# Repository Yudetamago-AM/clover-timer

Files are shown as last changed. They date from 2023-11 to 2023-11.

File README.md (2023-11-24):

# clover-timer
Simple Countdown Timer using Padauk MCU

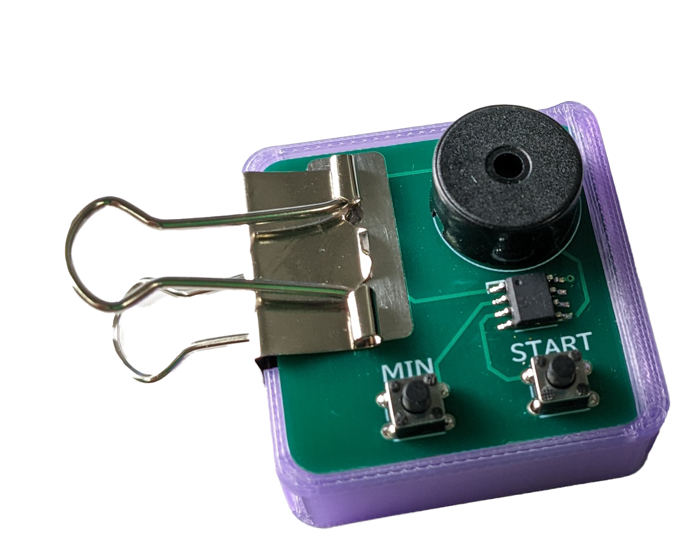
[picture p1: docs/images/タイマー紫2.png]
タイマー


## Docs
- [組み立て方（Japanese）](./docs/assembly-instruction.pdf)
- [補足資料（Japanese）](./docs/assembly-instruction-short.pdf)

## Schematic
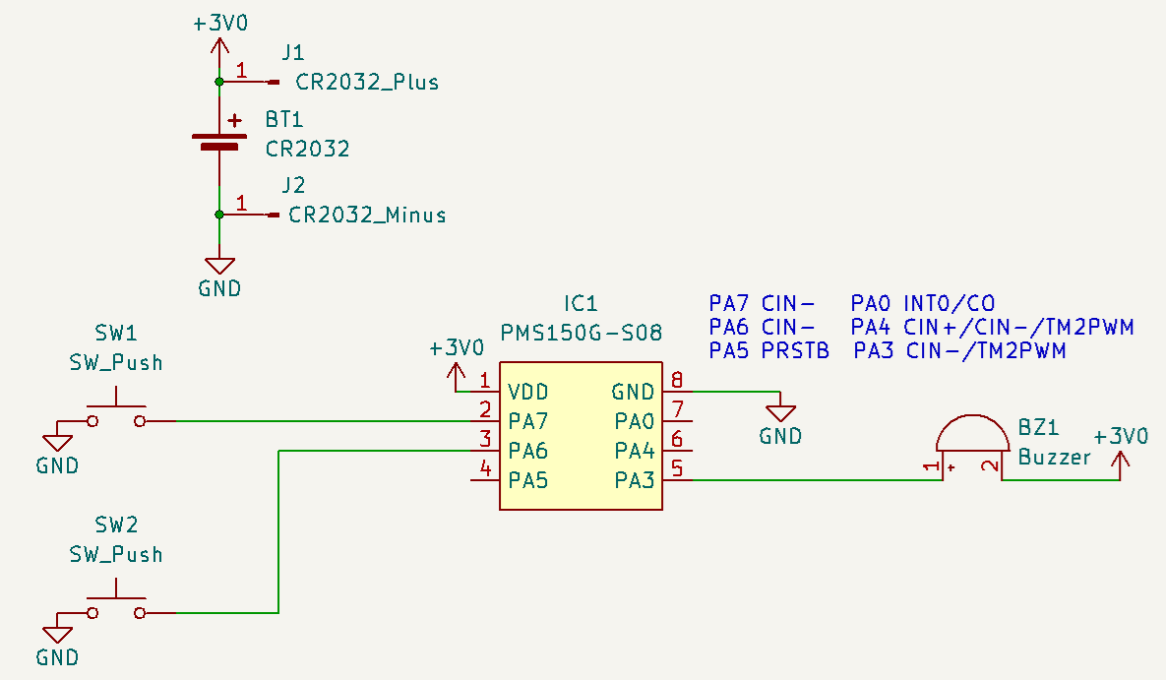
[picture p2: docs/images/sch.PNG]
schematic

Only supports PMS150G for now, but should be able to run on other Padauk MCUs with modifications.

### Power Consumption
- 350 μA (Countdown)
- 55  μA (Sleep)

Fall sleep in 2.5s

## BOM
| Ref | Part # | Description | Purchase | Price |
| --- | --- | --- | --- | ----- |
| IC1 | Padauk PMS150G | MCU | [LCSC](https://www.lcsc.com/product-detail/Microcontroller-Units-MCUs-MPUs-SOCs_PADAUK-Tech-PMS150G-S08_C2909819.html) | $0.04 each |
| SW1, SW2| TS4548CJ | Push Switch. Others are OK (Check footprint) | [LCSC](https://www.lcsc.com/product-detail/_SHOU-HAN-_C5359333.html) | $0.008 each |
| BZ1 | SFN-1407PA7.6 | Passive Buzzer | [LCSC](https://www.lcsc.com/product-detail/_S-S-_C360603.html) | $0.05 each |
| Battery | CR2032 | 3V Litium Battery Cell | - | $0.1~ each |
| - | Case | 3D printed case | Print by yourself | [STL](./case/bottom_rev0f.stl) |
| - | Binder Clip | Clip for Battery Case | - | $0.05~  each|
| - | Jigu(Optional) | Cardboard Jigu for Battery Case | Cut by yourself | [Data](./case/jigu_laser_rev2.dxf) |
| - | Magnet(Optional) | Φ18*5mm Magnet | - | $0.05~ each |

## Usage

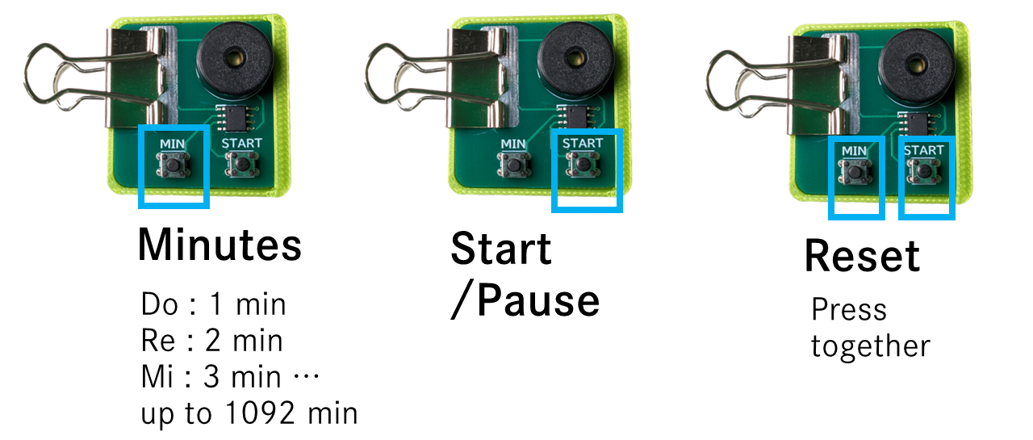
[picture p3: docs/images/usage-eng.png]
usage


## License
GPLv3

This project is based on:
- [Padauk-tone](https://github.com/Kashouryo/Padauk-tone) by Kashouryo, MIT License
- [pdk-digital-clock](https://github.com/serisman/pdk-digital-clock) by serisman, GPLv3

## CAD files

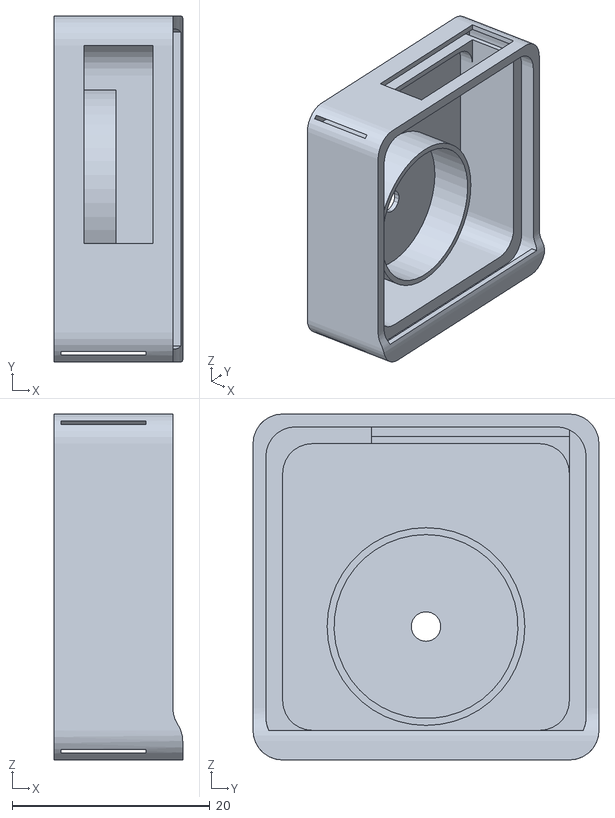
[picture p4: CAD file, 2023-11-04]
case/bottom_rev0f.stl
13.0 x 35.0 x 35.0

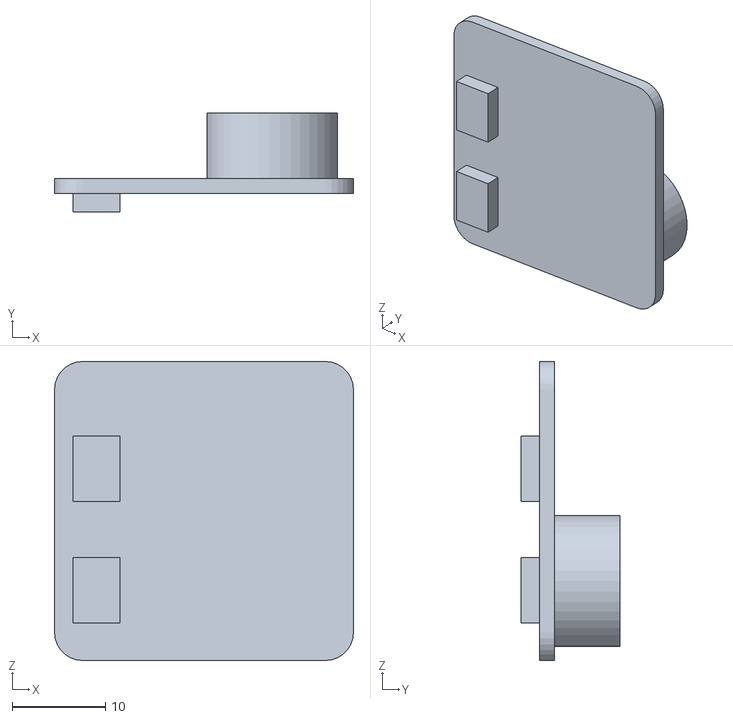
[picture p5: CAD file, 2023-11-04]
case/pcb_abs2.stl
32.0 x 10.6 x 32.0

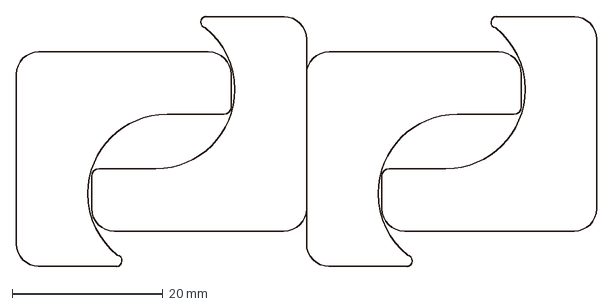
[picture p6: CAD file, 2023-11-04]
case/jigu_laser_rev2.dxf
77.0 x 33.2 mm

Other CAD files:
case/bottom_rev0f.ipt
case/pcb_abs.ipt

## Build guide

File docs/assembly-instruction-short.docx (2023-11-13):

「はんだ付けを体験しよう！」配付資料　　　　　　　　　　　　　　　　センサー街道プロジェクト

はんだ付けのやり方

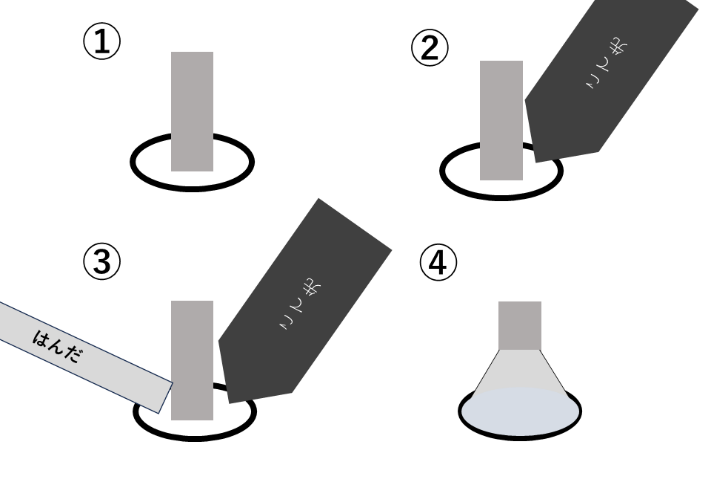
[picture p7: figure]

1. はんだ付け

背の低い部品から一つずつはんだ付けします。

  1 スイッチ→②ブザーの順です。

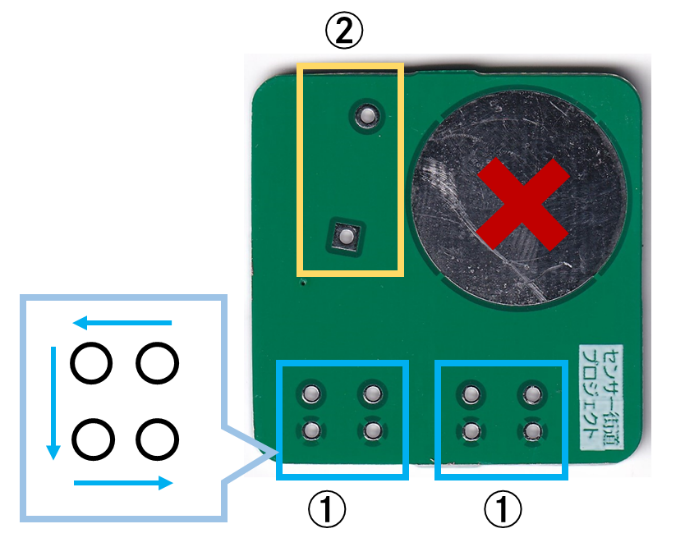
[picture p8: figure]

2. 組み立て
  1 磁石を押し込む かたいので、手伝います
  2 ジグをはめる

段ボールで できています。

  3 ボタン電池を入れる

磁石側が+です。

  4 基板をはめる
  5 クリップを付ける

電池ボックスと基板の固定の役割があります。

3. 使い方

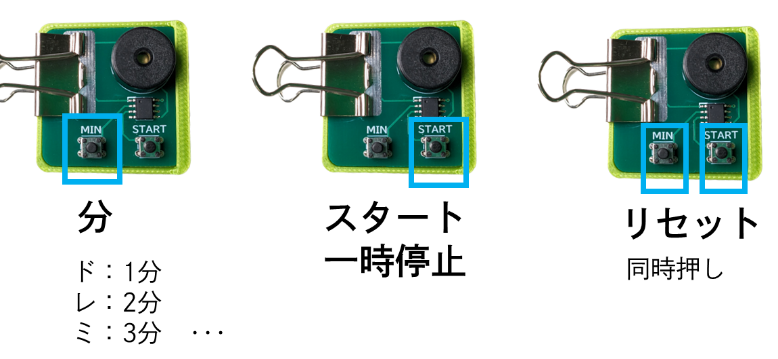
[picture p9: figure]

4. 仕様

使用電池 | CR2032 | スーパー等で売っています
消費電流 | 300μA | カウント時
消費電流 | 55μA | 待機時

5. ハードウェア構成

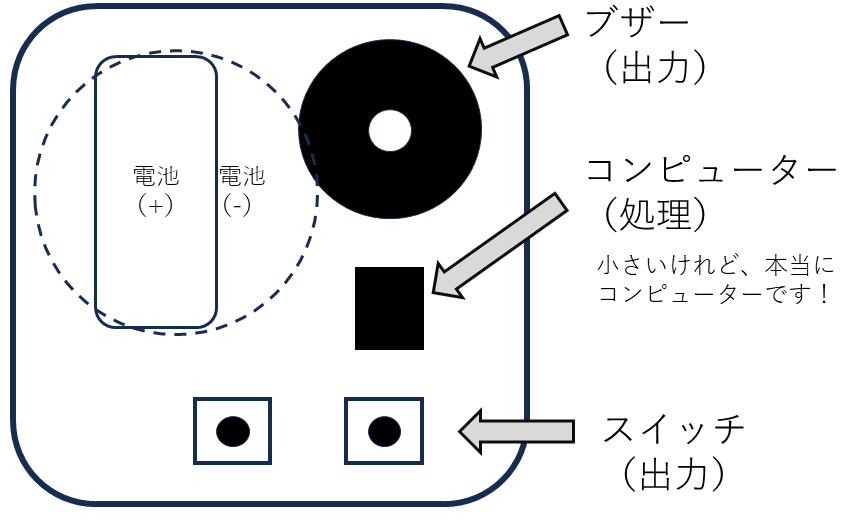
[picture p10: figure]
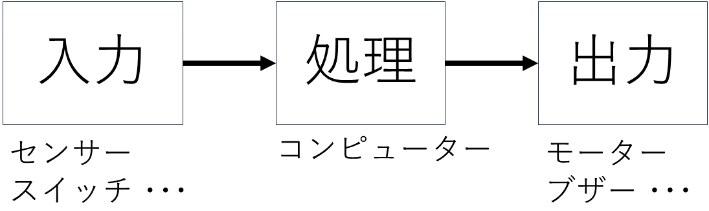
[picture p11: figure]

このタイマーと、スマートフォン、さらに自動車も本質的には同じ構成です。

6. 設計情報

このタイマーは、一定の条件下で誰でも自由に設計を利用・変更・再配布できます。

（ライセンス：GPLv3）

https://github.com/Yudetamago-AM/clover-timer

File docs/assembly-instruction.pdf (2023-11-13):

# はんだ付けを体験しよう！

センサー街道プロジェクト

京田辺校地総務課（同志社ローム記念館事務室）
同志社ローム記念館プロジェクト活動PR企画

内容

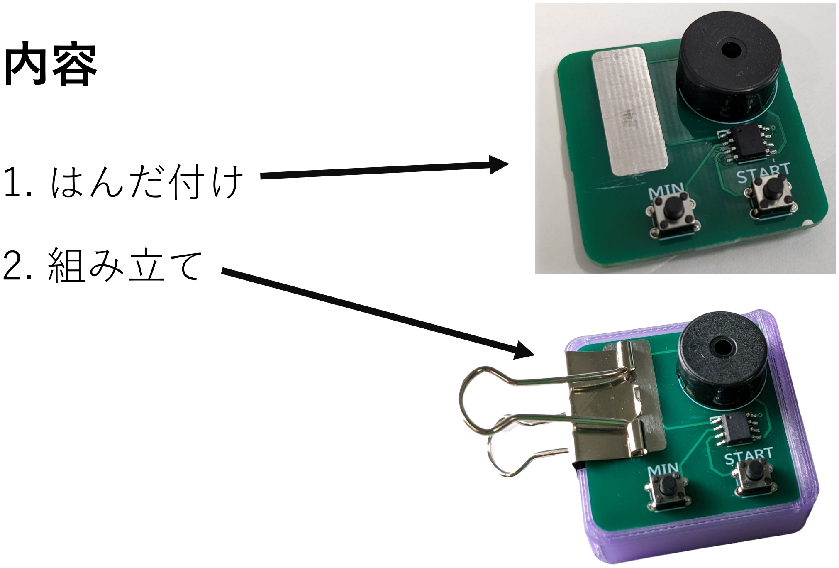
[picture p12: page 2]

## 1. はんだ付け 2. 組み立て

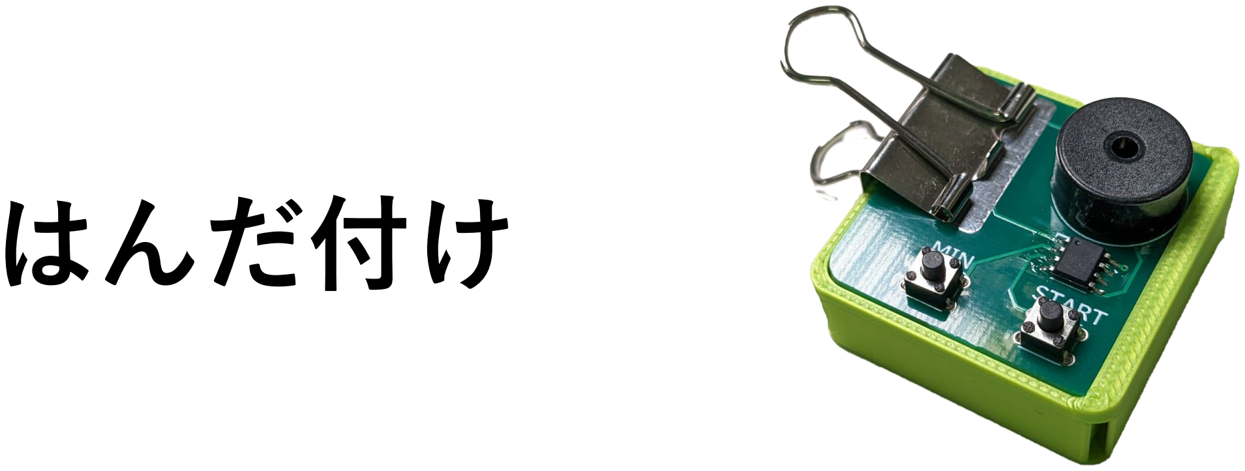
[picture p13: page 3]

# はんだ付け

# はんだごて

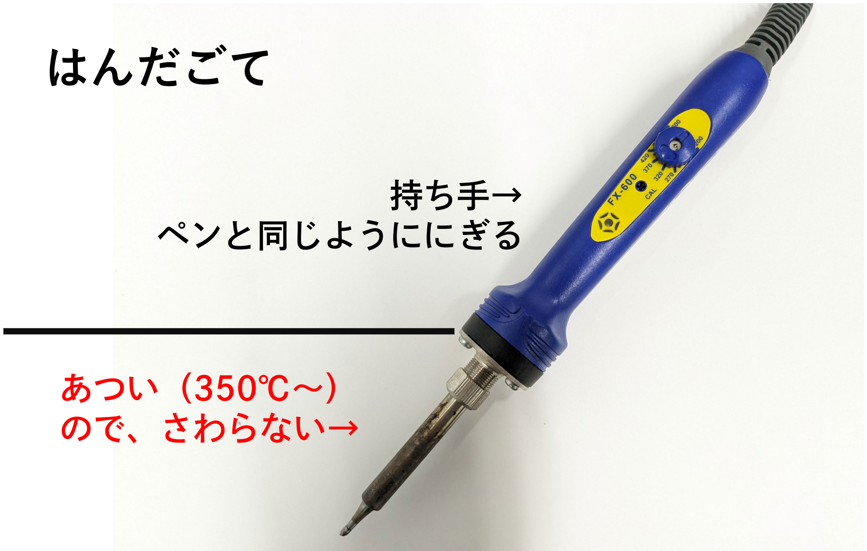
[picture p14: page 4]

### あつい（350℃～） ので、さわらない→

### 持ち手→ ペンと同じようににぎる

# はんだ付け

## 1. 部品をさしこむ

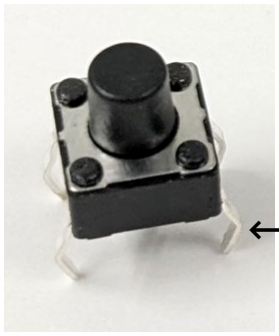
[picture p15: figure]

## 2. 部品の足をはんだ付けする

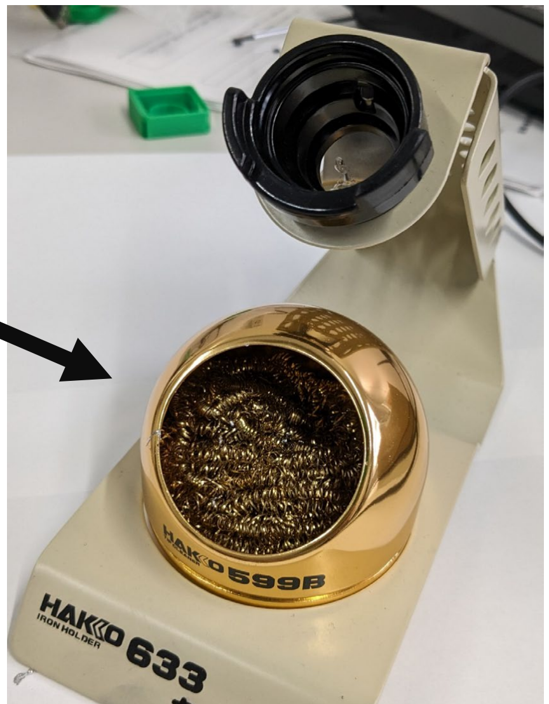
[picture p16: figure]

## 3. こて先をきれいにする

←足

# はんだ付けのやり方

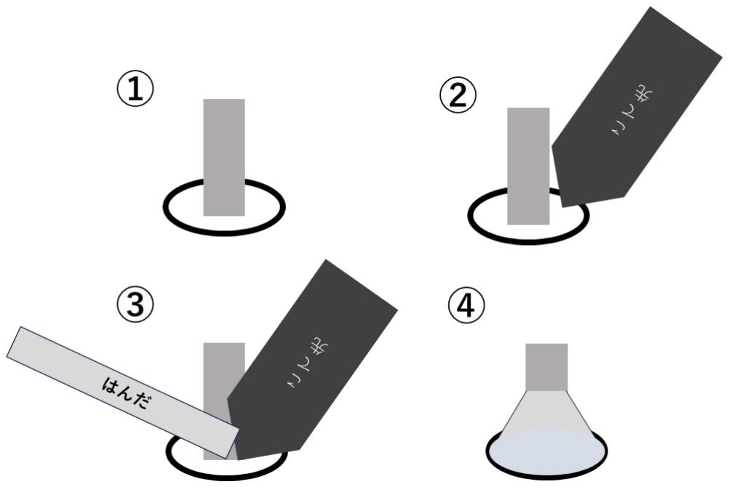
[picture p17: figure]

1. 部品を差し込み、基板（緑の
板）を裏返す
2. はんだごてのこて先を部品の足
と基板にあて予熱する
（1秒ほど）
3. 糸はんだを流し込む
4. 糸はんだとはんだごてを外し、
完成

部品

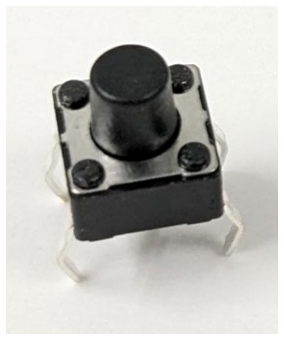
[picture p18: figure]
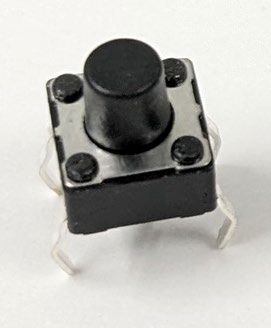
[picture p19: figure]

### 1. 押しボタン

2つ

### 2. ブザー

1つ

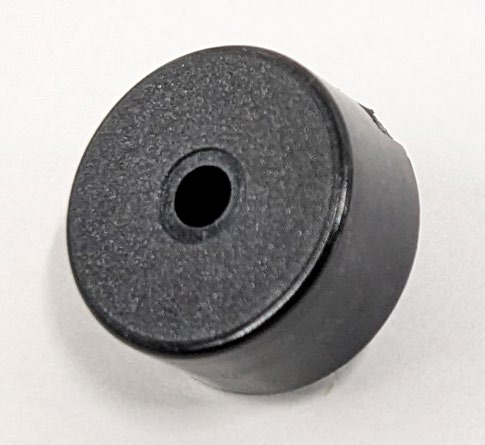
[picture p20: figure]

# はんだ付け

②

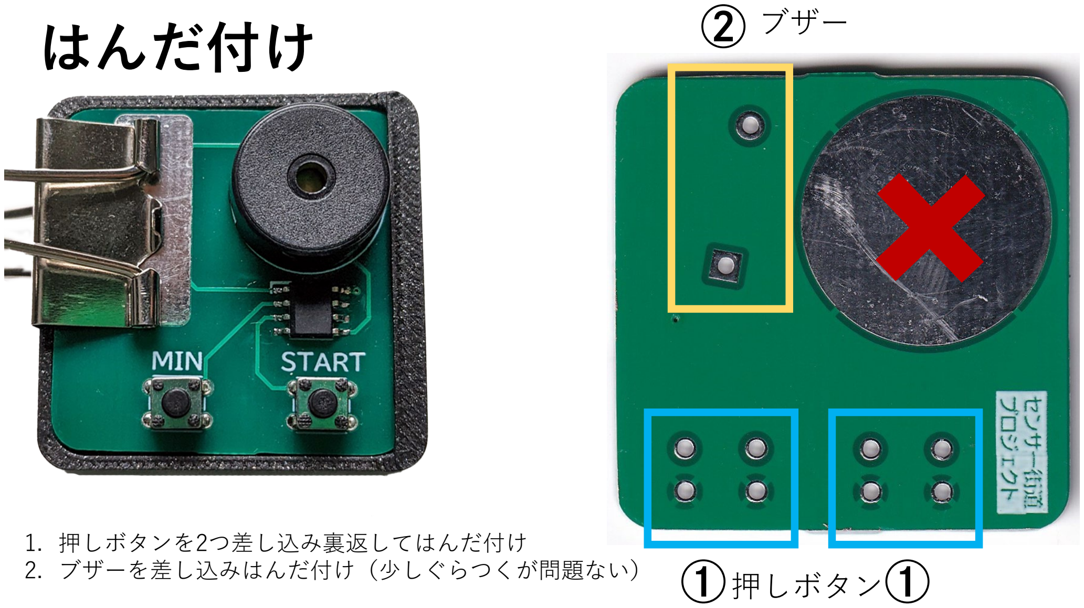
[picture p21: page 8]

① ①
押しボタン

ブザー

1. 押しボタンを2つ差し込み裏返してはんだ付け
2. ブザーを差し込みはんだ付け（少しぐらつくが問題ない）

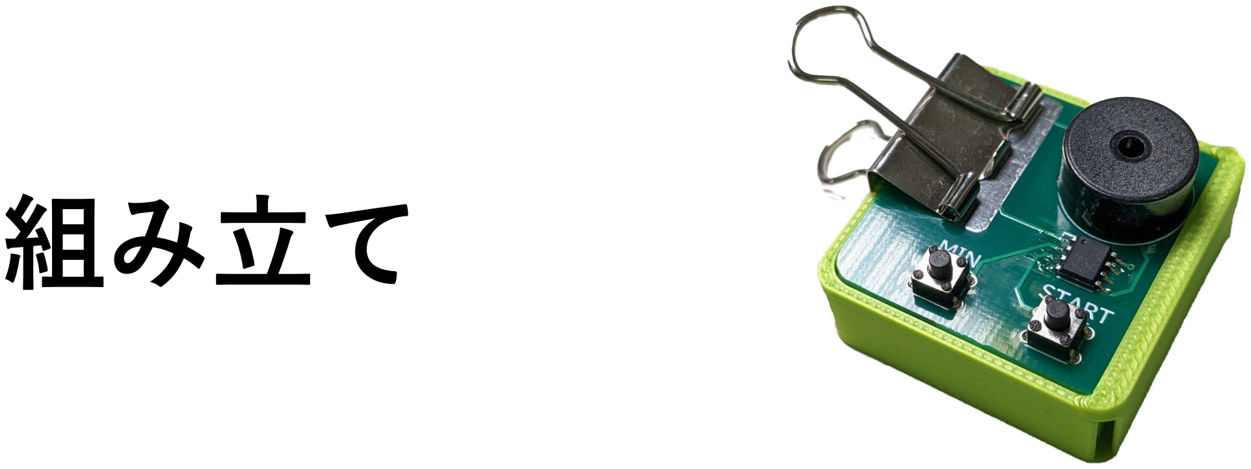
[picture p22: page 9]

# 組み立て

部品

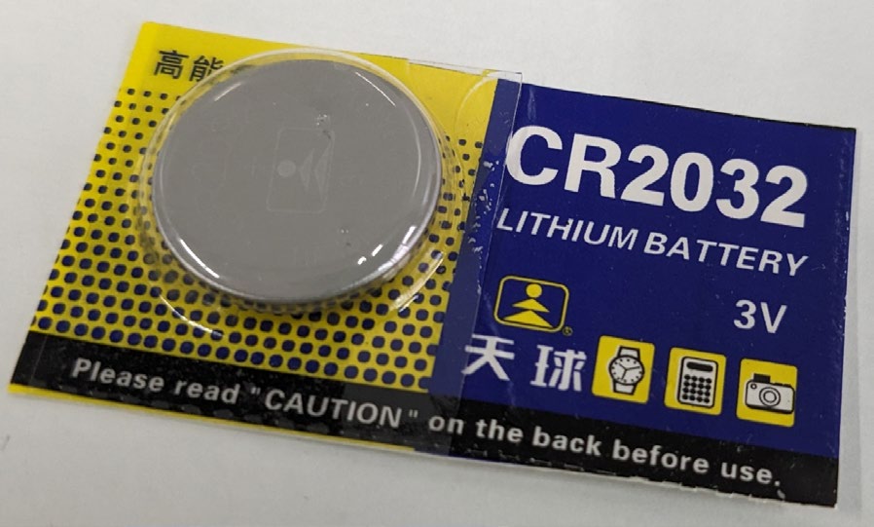
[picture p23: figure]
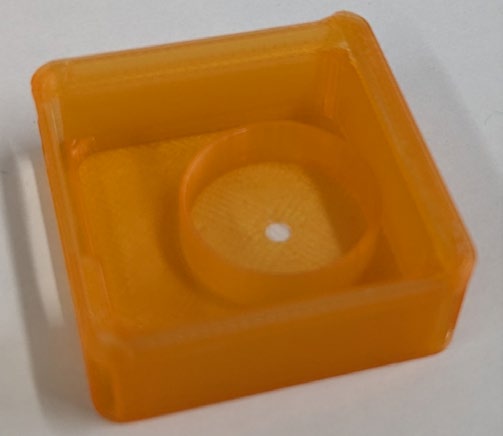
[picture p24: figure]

### 1. ケース

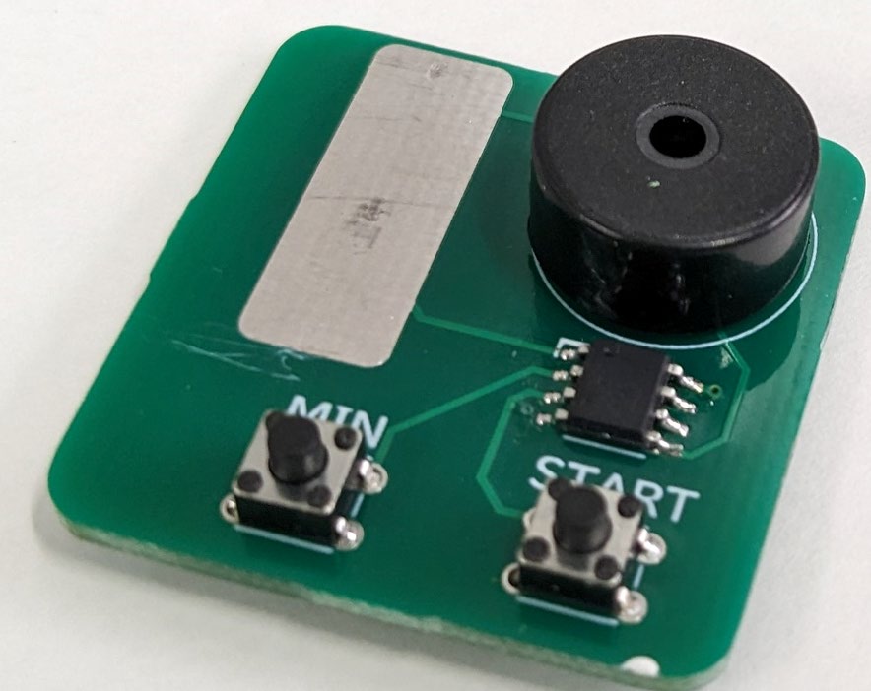
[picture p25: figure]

2. 磁石

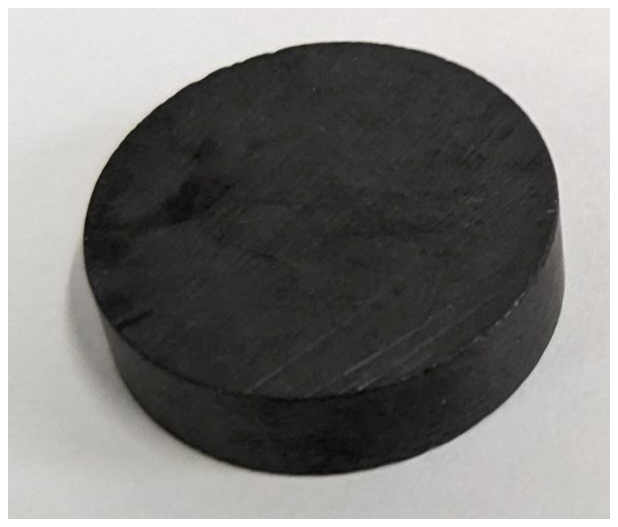
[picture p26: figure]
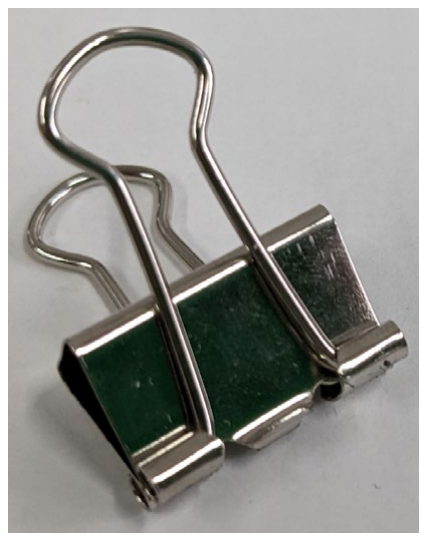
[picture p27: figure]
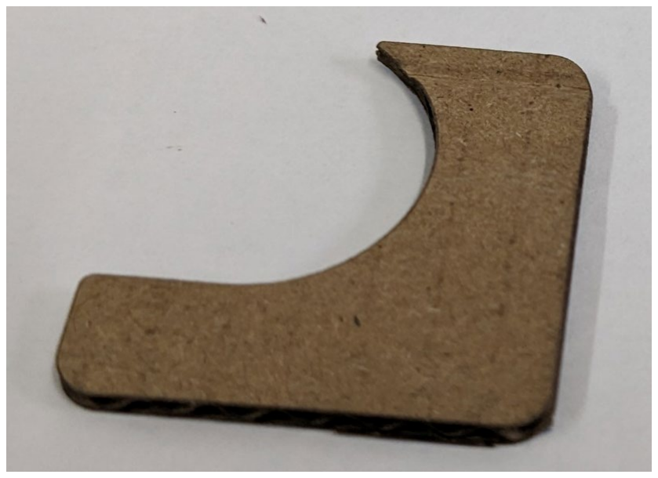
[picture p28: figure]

### 3. ジグ（治具）

### 4. ボタン電池

5. 基板

### 6. クリップ

# 磁石を押しこむ

### かたいので、手伝います （呼んでください！）

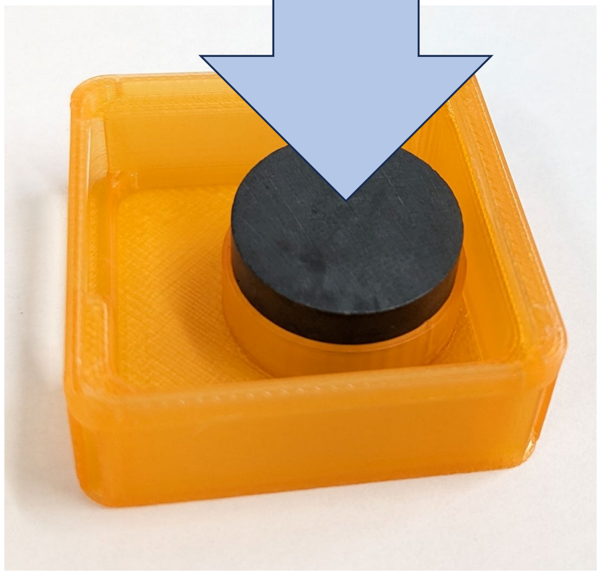
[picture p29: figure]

### 押し込んである場合は次へ

力

# ジグをはめる

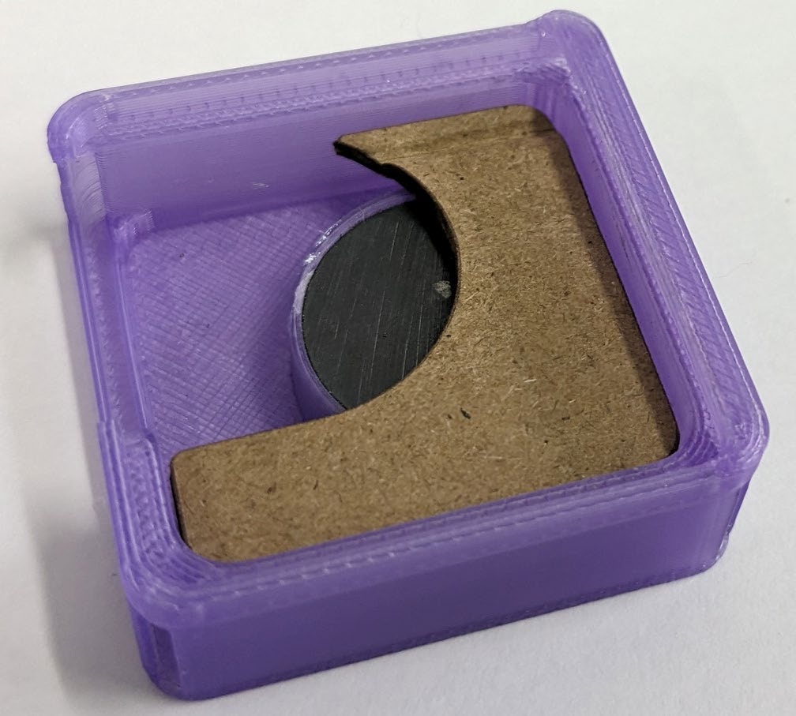
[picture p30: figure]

### - 向きに注意

# ボタン電池を入れる

ざらざらの面が表 | （開け方）

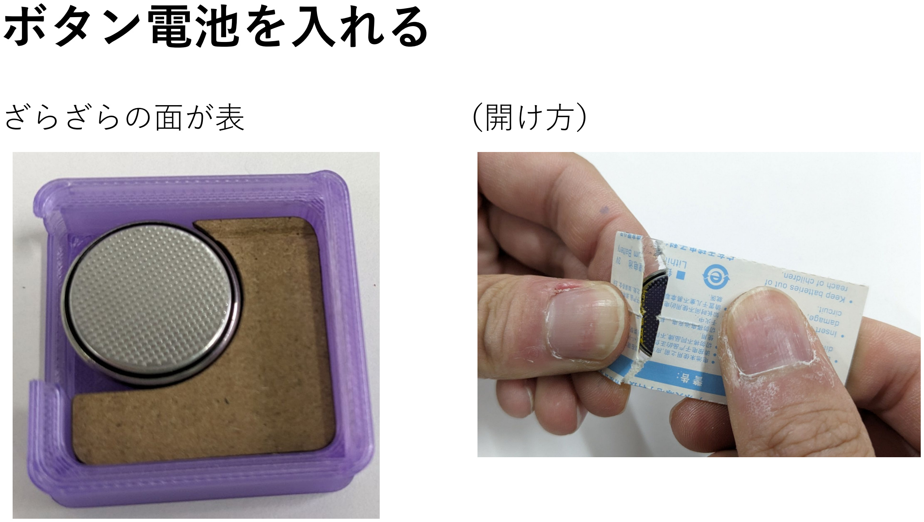
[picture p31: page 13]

# 基板をはめる ①

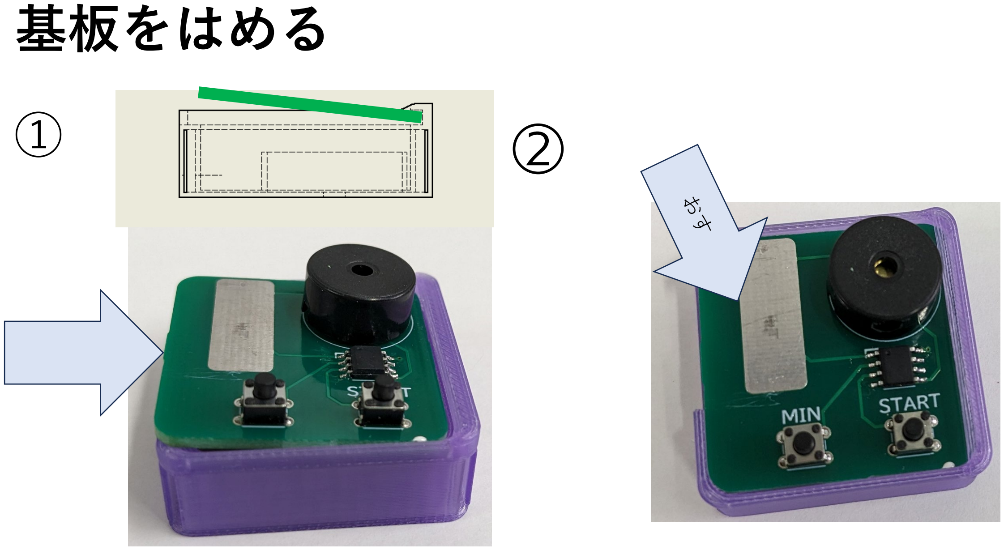
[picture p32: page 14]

②

# クリップをつける

### - ボタン電池と基板をはさむ

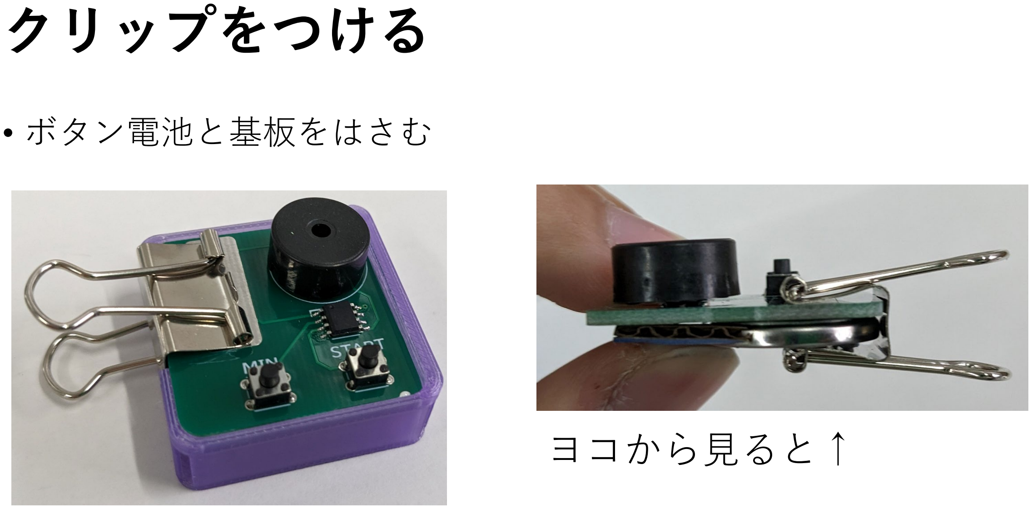
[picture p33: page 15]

## ヨコから見ると↑

# 使い方

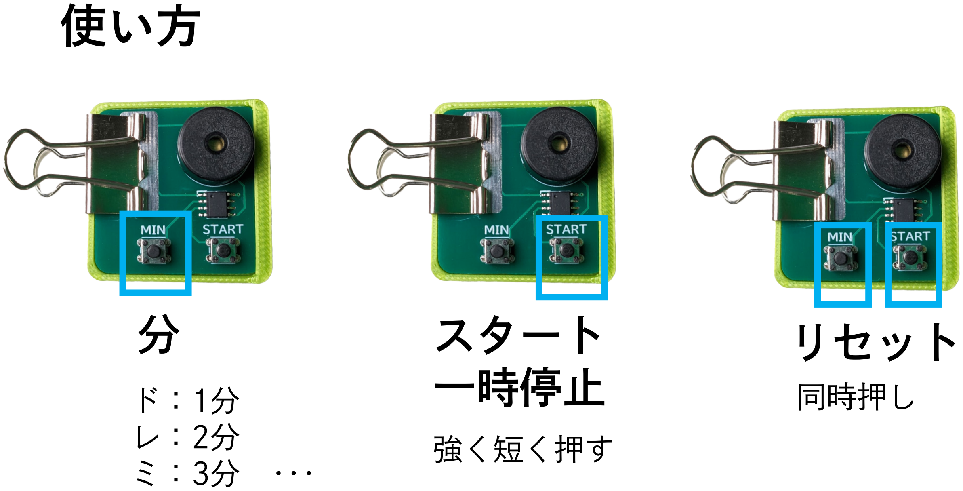
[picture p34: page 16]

分

ド：1分
レ：2分
ミ：3分 ･･･

## スタート 一時停止

## リセット

同時押し
強く短く押す

# トラブルシューティング

### - ボタンを押しても音が鳴らない

- ボタンのはんだ付けが不足しているかもしれません。ボタンの足の根 元にあてるイメージではんだ付けし直してみてください。

### - ボタンを押してないのに音が鳴り続ける

- ボタンのはんだ付けが多すぎるかもしれません。足と足の間がハンダ でつながってしまっていないか確認してください。
- はんだ吸い取り線などで、余分なはんだを取り除いてみてください。

# トラブルシューティング

### - 設定した時間になっても音が鳴らない

- スタートボタンを長く押しすぎてしまった（スタートして、一時停止 した）かも知れません。
- 一回、両方のボタンを押して、もう一度試してみてください。

# よくある質問

### - 何分まで測れる？

- 1092分まで
- 2^16=65536秒まで測れるので、65536/60 ≒ 1092分

### - 電池はどのくらい持つ？

- 150日くらい（のはず）
- ボタン電池(CR2023)の容量を220mAhとする。待機時55μA消費する。 動作している時間<<待機してる時間と考えて、
220m/55μ= 4000 時間、4000/24 ≒ 166日 自然放電もあると考えて、150日くらい？
- キット付属の電池は安いやつなので、そんなに持たないかも

完成！

### 1分にセットして音が鳴るかやってみましょう！

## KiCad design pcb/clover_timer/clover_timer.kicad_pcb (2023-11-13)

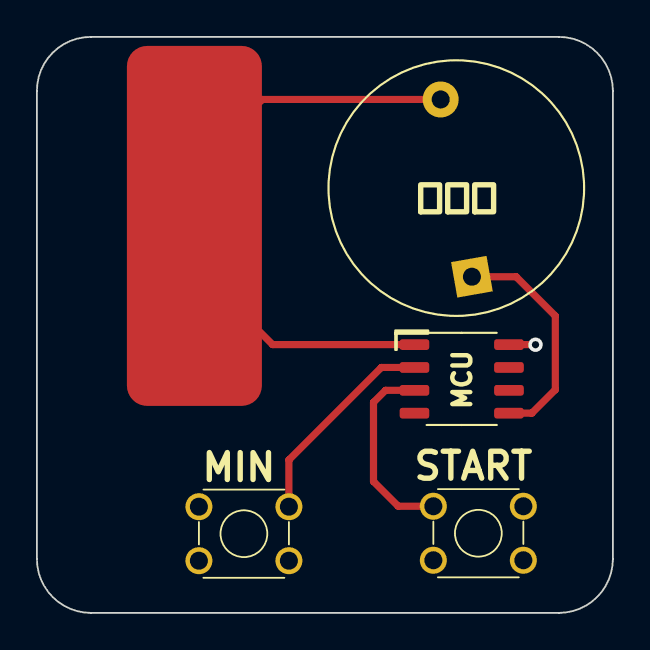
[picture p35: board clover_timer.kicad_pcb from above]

Board: 2 copper layers, 32.0 x 32.0 mm, 6 parts (1 on the bottom side), 5 nets.

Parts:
BZ1: Buzzer; Buzzer_D14mm_H7mm_P10mm
IC1: PMS150G-S08; SOP-8_3.9x4.9mm_P1.27mm
J1: CR2032_Plus
J2: CR2032_Minus; CR2032_GND
SW1, SW2: SW_Push; SW_TS4548CJ

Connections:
+3V0: BZ1.2 (+), IC1.1 (VDD), J1.1
GND: IC1.8 (GND), J2.1, SW1.1, SW2.1
unnamed: BZ1.1 (-), IC1.5 (PA3)
unnamed: IC1.3 (PA6), SW2.2
unnamed: IC1.2 (PA7), SW1.2

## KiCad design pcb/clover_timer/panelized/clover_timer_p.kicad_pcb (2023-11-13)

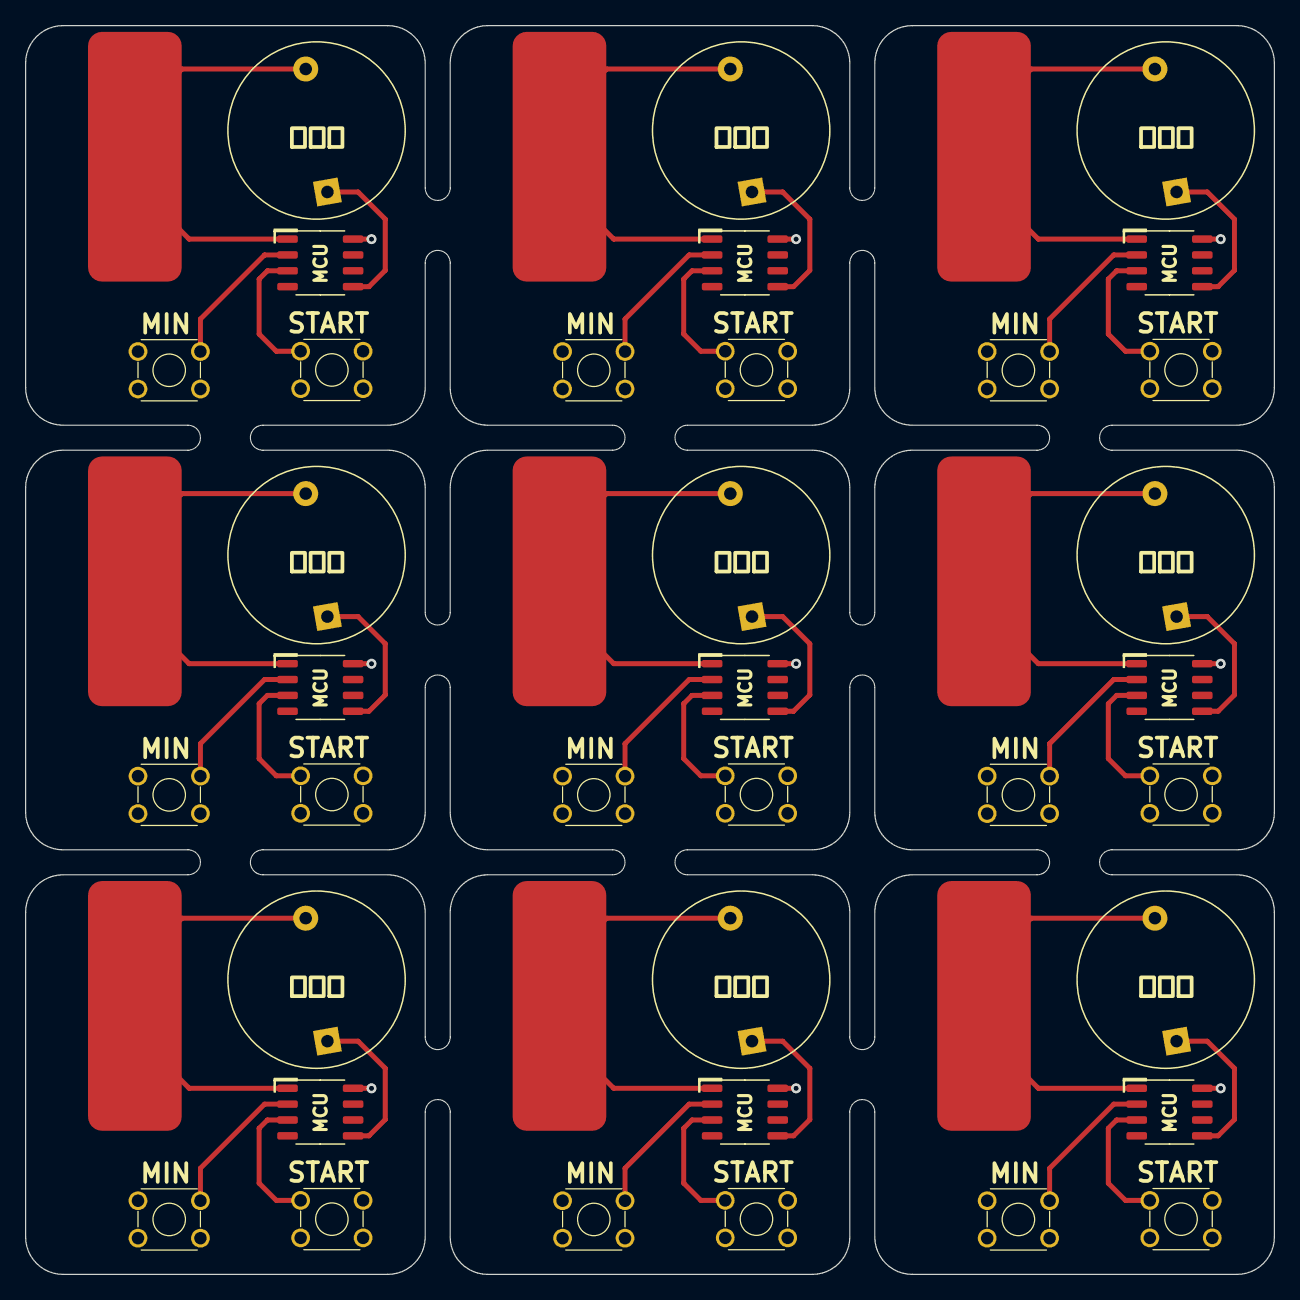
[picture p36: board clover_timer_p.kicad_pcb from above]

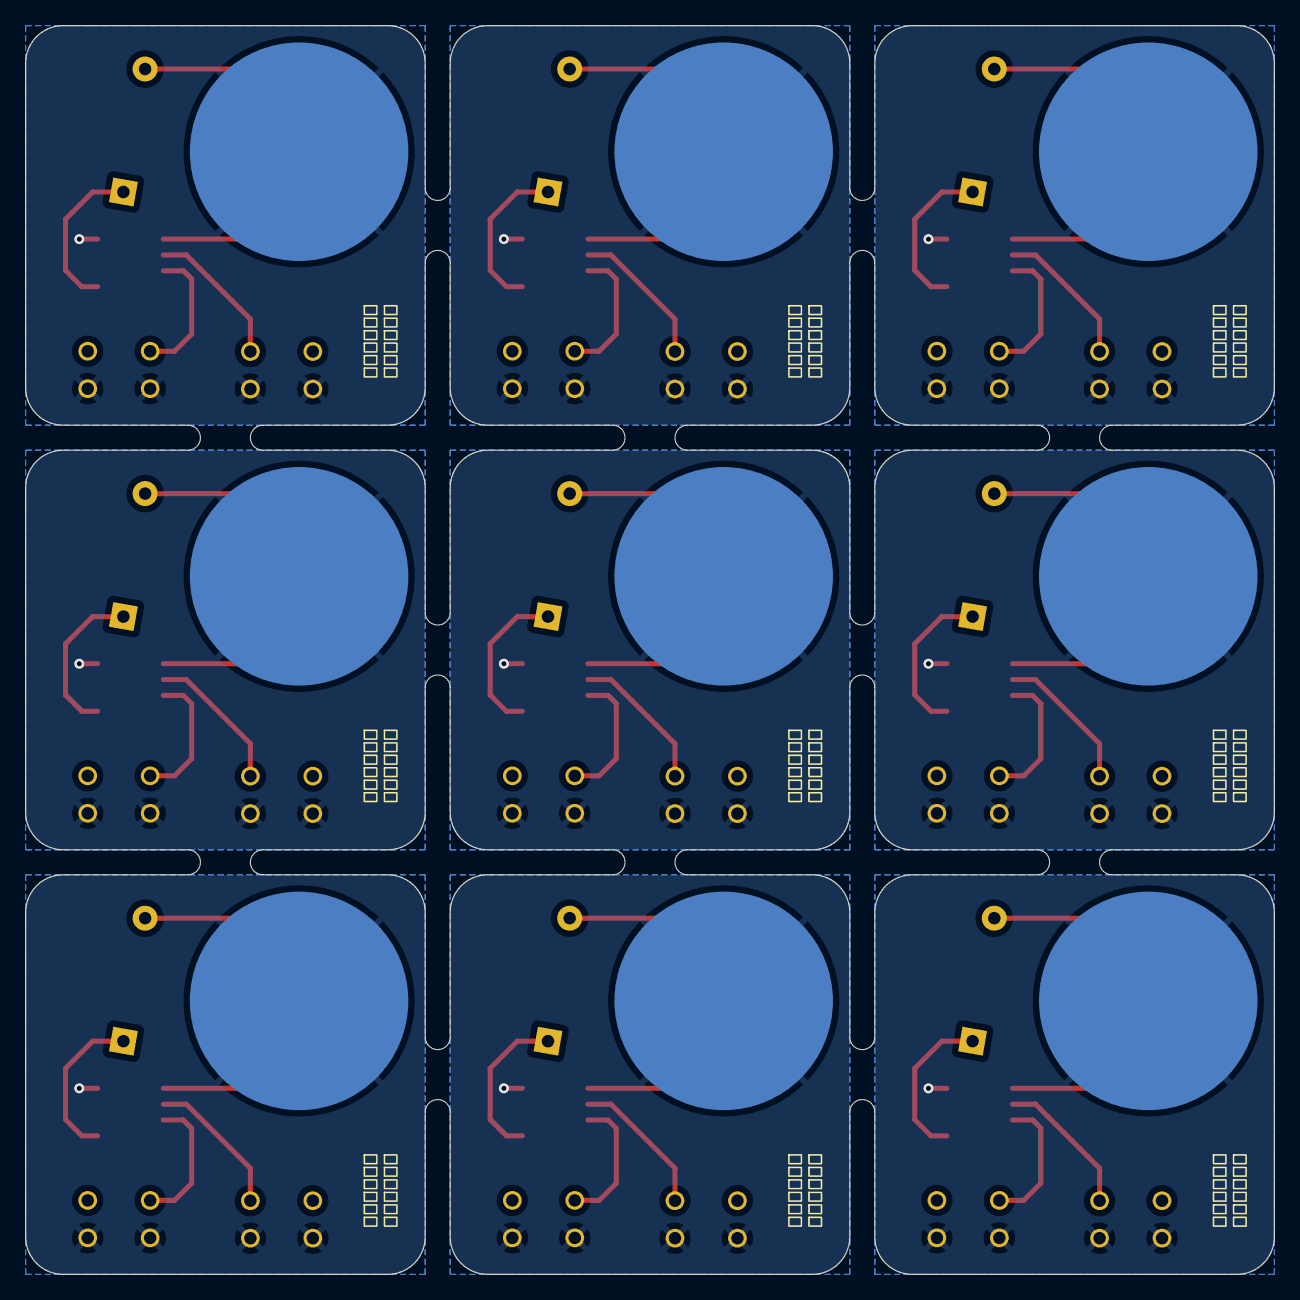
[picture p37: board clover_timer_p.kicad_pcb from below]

Board: 2 copper layers, 100.0 x 100.0 mm, 54 parts (9 on the bottom side), 5 nets.

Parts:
BZ1, BZ2, BZ3, BZ4, BZ5, BZ6, BZ7, BZ8, BZ9: Buzzer; Buzzer_D14mm_H7mm_P10mm
IC1, IC2, IC3, IC4, IC5, IC6, IC7, IC8, IC9: PMS150G-S08; SOP-8_3.9x4.9mm_P1.27mm
J1, J3, J5, J7, J9, J11, J13, J15, J17: CR2032_Plus
J2, J4, J6, J8, J10, J12, J14, J16, J18: CR2032_Minus; CR2032_GND
SW1, SW2, SW3, SW4, SW5, SW6, SW7, SW8, SW9, SW10, SW11, SW12, SW13, SW14, SW15, SW16, SW17, SW18: SW_Push; SW_TS4548CJ

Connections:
+3V0: BZ1.2 (+), BZ2.2 (+), BZ3.2 (+), BZ4.2 (+), BZ5.2 (+), BZ6.2 (+), BZ7.2 (+), BZ8.2 (+), BZ9.2 (+), IC1.1 (VDD), IC2.1 (VDD), IC3.1 (VDD), IC4.1 (VDD), IC5.1 (VDD), IC6.1 (VDD), IC7.1 (VDD), IC8.1 (VDD), IC9.1 (VDD), J1.1, J3.1, J5.1, J7.1, J9.1, J11.1, J13.1, J15.1, J17.1
GND: IC1.8 (GND), IC2.8 (GND), IC3.8 (GND), IC4.8 (GND), IC5.8 (GND), IC6.8 (GND), IC7.8 (GND), IC8.8 (GND), IC9.8 (GND), J2.1, J4.1, J6.1, J8.1, J10.1, J12.1, J14.1, J16.1, J18.1, SW1.1, SW2.1, SW3.1, SW4.1, SW5.1, SW6.1, SW7.1, SW8.1, SW9.1, SW10.1, SW11.1, SW12.1, SW13.1, SW14.1, SW15.1, SW16.1, SW17.1, SW18.1
unnamed: BZ1.1 (-), BZ2.1 (-), BZ3.1 (-), BZ4.1 (-), BZ5.1 (-), BZ6.1 (-), BZ7.1 (-), BZ8.1 (-), BZ9.1 (-), IC1.5 (PA3), IC2.5 (PA3), IC3.5 (PA3), IC4.5 (PA3), IC5.5 (PA3), IC6.5 (PA3), IC7.5 (PA3), IC8.5 (PA3), IC9.5 (PA3)
unnamed: IC1.3 (PA6), IC2.3 (PA6), IC3.3 (PA6), IC4.3 (PA6), IC5.3 (PA6), IC6.3 (PA6), IC7.3 (PA6), IC8.3 (PA6), IC9.3 (PA6), SW2.2, SW4.2, SW6.2, SW8.2, SW10.2, SW12.2, SW14.2, SW16.2, SW18.2
unnamed: IC1.2 (PA7), IC2.2 (PA7), IC3.2 (PA7), IC4.2 (PA7), IC5.2 (PA7), IC6.2 (PA7), IC7.2 (PA7), IC8.2 (PA7), IC9.2 (PA7), SW1.2, SW3.2, SW5.2, SW7.2, SW9.2, SW11.2, SW13.2, SW15.2, SW17.2

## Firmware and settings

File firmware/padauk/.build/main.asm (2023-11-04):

;--------------------------------------------------------
; File Created by SDCC : free open source ANSI-C Compiler
; Version 4.2.0 #13081 (Linux)
;--------------------------------------------------------
	.module main
	.optsdcc -mpdk13
	

; default segment ordering in RAM for linker
	.area DATA
	.area OSEG (OVR,DATA)

;--------------------------------------------------------
; Public variables in this module
;--------------------------------------------------------
	.globl _main
	.globl _interrupt
	.globl __sdcc_external_startup
	.globl _tonePA3ND
	.globl _noTone
	.globl __misc
	.globl __gpcs
	.globl __gpcc
	.globl __bgtr
	.globl __tm2b
	.globl __tm2s
	.globl __tm2ct
	.globl __tm2c
	.globl __t16c
	.globl __t16m
	.globl __papl
	.globl __paph
	.globl __pac
	.globl __pa
	.globl __padier
	.globl __integs
	.globl __intrq
	.globl __inten
	.globl __eoscr
	.globl __ilrcr
	.globl __ihrcr
	.globl __clkmd
	.globl __sp
	.globl __flag
	.globl _idle_cnt
	.globl _set_seconds
	.globl _seconds
	.globl _tone_cnt
	.globl _mode_now
	.globl _prev_quarter_seconds
	.globl _quarter_seconds
	.globl _tonePA3ND_PARM_1
;--------------------------------------------------------
; special function registers
;--------------------------------------------------------
	.area RSEG (ABS)
	.org 0x0000
__flag	=	0x0000
__sp	=	0x0002
__clkmd	=	0x0003
__ihrcr	=	0x000b
__ilrcr	=	0x001f
__eoscr	=	0x000a
__inten	=	0x0004
__intrq	=	0x0005
__integs	=	0x000c
__padier	=	0x000d
__pa	=	0x0010
__pac	=	0x0011
__paph	=	0x0012
__papl	=	0x0013
__t16m	=	0x0006
__t16c::
	.ds 2
__tm2c	=	0x001c
__tm2ct	=	0x001d
__tm2s	=	0x0017
__tm2b	=	0x0009
__bgtr	=	0x0019
__gpcc	=	0x001a
__gpcs	=	0x001e
__misc	=	0x001b
;--------------------------------------------------------
; ram data
;--------------------------------------------------------
	.area DATA
_tonePA3ND_PARM_1:
	.ds 1
_quarter_seconds::
	.ds 1
_prev_quarter_seconds::
	.ds 1
_mode_now::
	.ds 1
_tone_cnt::
	.ds 1
_seconds::
	.ds 2
_set_seconds::
	.ds 2
_idle_cnt::
	.ds 1
;--------------------------------------------------------
; overlayable items in ram
;--------------------------------------------------------
;--------------------------------------------------------
; Stack segment in internal ram
;--------------------------------------------------------
	.area	SSEG
__start__stack:
	.ds	1

;--------------------------------------------------------
; absolute external ram data
;--------------------------------------------------------
	.area DABS (ABS)
;--------------------------------------------------------
; interrupt vector
;--------------------------------------------------------
	.area HOME
__interrupt_vect:
	.area	HEADER (ABS)
	.org	 0x0020
	goto	_interrupt
;--------------------------------------------------------
; global & static initialisations
;--------------------------------------------------------
	.area HOME
	.area GSINIT
	.area GSFINAL
	.area GSINIT
	.area	PREG (ABS)
	.org 0x00
p::
	.ds 2
	.area	HEADER (ABS)
	.org 0x0000
	nop
	clear	p+1
	mov	a, #s_OSEG
	add	a, #l_OSEG + 1
	and	a, #0xfe
	mov.io	sp, a
	call	__sdcc_external_startup
	goto	s_GSINIT
	.area GSINIT
__sdcc_init_data:
	mov	a, #s_DATA
	mov	p, a
	goto	00002$
00001$:
	mov	a, #0x00
	idxm	p, a
	inc	p
	mov	a, #s_DATA
00002$:
	add	a, #l_DATA
	ceqsn	a, p
	goto	00001$
;	main.c: 20: uint8_t prev_quarter_seconds = 0;
	clear	_prev_quarter_seconds+0
;	main.c: 21: uint8_t mode_now = MODE_WAIT;
	clear	_mode_now+0
;	main.c: 22: uint8_t tone_cnt = 0;
	clear	_tone_cnt+0
;	main.c: 23: uint16_t seconds = 0, set_seconds = 0;
	clear	_seconds+0
	clear	_seconds+1
;	main.c: 23: uint8_t idle_cnt = IDLE_DUR; 
	clear	_set_seconds+0
	clear	_set_seconds+1
;	main.c: 24: 
	mov	a, #0x02
	mov	_idle_cnt+0, a
	.area GSFINAL
	goto	__sdcc_program_startup
;--------------------------------------------------------
; Home
;--------------------------------------------------------
	.area HOME
	.area HOME
__sdcc_program_startup:
	goto	_main
;	return from main will return to caller
;--------------------------------------------------------
; code
;--------------------------------------------------------
	.area CODE
;	./Padauk-tone/tone.h: 33: void noTone(void){
;	-----------------------------------------
;	 function noTone
;	-----------------------------------------
_noTone:
;	./Padauk-tone/tone.h: 34: TM2C = 0x00; PA |= (1<<BUZZER_BIT);
	mov	a, #0x00
	mov.io	__tm2c, a
	set1.io	__pa, #3
;	./Padauk-tone/tone.h: 35: }
	ret
;	./Padauk-tone/tone.h: 38: void tonePA3ND(uint8_t note){
;	-----------------------------------------
;	 function tonePA3ND
;	-----------------------------------------
_tonePA3ND:
;	./Padauk-tone/tone.h: 39: TM2B = 0x7F;
	mov	a, #0x7f
	mov.io	__tm2b, a
;	./Padauk-tone/tone.h: 40: switch(note){
	mov	a, #0x12
	sub	a, _tonePA3ND_PARM_1+0
	t0sn.io	f, c
	goto	00118$
	mov	a, _tonePA3ND_PARM_1+0
	add	a, #0x01
	pcadd	a
	goto	#00118$
	goto	#00101$
	goto	#00102$
	goto	#00103$
	goto	#00104$
	goto	#00105$
	goto	#00106$
	goto	#00107$
	goto	#00108$
	goto	#00118$
	goto	#00118$
	goto	#00109$
	goto	#00110$
	goto	#00111$
	goto	#00112$
	goto	#00113$
	goto	#00114$
	goto	#00115$
	goto	#00116$
;	./Padauk-tone/tone.h: 41: case 1:
00101$:
;	./Padauk-tone/tone.h: 42: TM2S = tone_c4;
	mov	a, #0x31
	mov.io	__tm2s, a
;	./Padauk-tone/tone.h: 43: break;
	goto	00118$
;	./Padauk-tone/tone.h: 44: case 2:
00102$:
;	./Padauk-tone/tone.h: 45: TM2S = tone_d4;
	mov	a, #0x2f
	mov.io	__tm2s, a
;	./Padauk-tone/tone.h: 46: break;
	goto	00118$
;	./Padauk-tone/tone.h: 47: case 3:
00103$:
;	./Padauk-tone/tone.h: 48: TM2S = tone_e4;
	mov	a, #0x2d
	mov.io	__tm2s, a
;	./Padauk-tone/tone.h: 49: break;
	goto	00118$
;	./Padauk-tone/tone.h: 50: case 4:
00104$:
;	./Padauk-tone/tone.h: 51: TM2S = tone_f4;
	mov	a, #0x2c
	mov.io	__tm2s, a
;	./Padauk-tone/tone.h: 52: break;
	goto	00118$
;	./Padauk-tone/tone.h: 53: case 5:
00105$:
;	./Padauk-tone/tone.h: 54: TM2S = tone_g4;
	mov	a, #0x2b
	mov.io	__tm2s, a
;	./Padauk-tone/tone.h: 55: break;
	goto	00118$
;	./Padauk-tone/tone.h: 56: case 6:
00106$:
;	./Padauk-tone/tone.h: 57: TM2S = tone_a4;
	mov	a, #0x2a
	mov.io	__tm2s, a
;	./Padauk-tone/tone.h: 58: break;
	goto	00118$
;	./Padauk-tone/tone.h: 59: case 7:
00107$:
;	./Padauk-tone/tone.h: 60: TM2S = tone_b4;
	mov	a, #0x29
	mov.io	__tm2s, a
;	./Padauk-tone/tone.h: 61: break;
	goto	00118$
;	./Padauk-tone/tone.h: 62: case 8:
00108$:
;	./Padauk-tone/tone.h: 63: TM2S = tone_c5;
	mov	a, #0x28
	mov.io	__tm2s, a
;	./Padauk-tone/tone.h: 64: break;
	goto	00118$
;	./Padauk-tone/tone.h: 65: case 11:
00109$:
;	./Padauk-tone/tone.h: 66: TM2S = tone_c5;
	mov	a, #0x28
	mov.io	__tm2s, a
;	./Padauk-tone/tone.h: 67: break;
	goto	00118$
;	./Padauk-tone/tone.h: 68: case 12:
00110$:
;	./Padauk-tone/tone.h: 69: TM2S = tone_d5;
	mov	a, #0x27
	mov.io	__tm2s, a
;	./Padauk-tone/tone.h: 70: break;
	goto	00118$
;	./Padauk-tone/tone.h: 71: case 13:
00111$:
;	./Padauk-tone/tone.h: 72: TM2S = tone_e5;
	mov	a, #0x1c
	mov.io	__tm2s, a
;	./Padauk-tone/tone.h: 73: break;
	goto	00118$
;	./Padauk-tone/tone.h: 74: case 14:
00112$:
;	./Padauk-tone/tone.h: 75: TM2S = tone_f5;
	mov	a, #0x1a
	mov.io	__tm2s, a
;	./Padauk-tone/tone.h: 76: break;
	goto	00118$
;	./Padauk-tone/tone.h: 77: case 15:
00113$:
;	./Padauk-tone/tone.h: 78: TM2S = tone_g5;
	mov	a, #0x17
	mov.io	__tm2s, a
;	./Padauk-tone/tone.h: 79: break;
	goto	00118$
;	./Padauk-tone/tone.h: 80: case 16:
00114$:
;	./Padauk-tone/tone.h: 81: TM2S = tone_a5;
	mov	a, #0x15
	mov.io	__tm2s, a
;	./Padauk-tone/tone.h: 82: break;
	goto	00118$
;	./Padauk-tone/tone.h: 83: case 17:
00115$:
;	./Padauk-tone/tone.h: 84: TM2S = tone_b5;
	mov	a, #0x13
	mov.io	__tm2s, a
;	./Padauk-tone/tone.h: 85: break;
	goto	00118$
;	./Padauk-tone/tone.h: 86: case 18:
00116$:
;	./Padauk-tone/tone.h: 87: TM2S = tone_c6;
	mov	a, #0x11
	mov.io	__tm2s, a
;	./Padauk-tone/tone.h: 91: }
00118$:
;	./Padauk-tone/tone.h: 92: TM2C = (uint8_t)(TM2C_INVERT_OUT | TM2C_MODE_PWM | TM2C_OUT_PA3 | TM2C_CLK_IHRC);
	mov	a, #0x2b
	mov.io	__tm2c, a
;	./Padauk-tone/tone.h: 93: }
	ret
;	main.c: 26: unsigned char _sdcc_external_startup(void) {
;	-----------------------------------------
;	 function _sdcc_external_startup
;	-----------------------------------------
__sdcc_external_startup:
;	main.c: 29: PDK_SET_SYSCLOCK(SYSCLOCK_IHRC_500KHZ);
	mov	a, #0x7c
	mov.io	__clkmd, a
;	main.c: 30: EASY_PDK_CALIBRATE_IHRC(524288, TARGET_VDD_MV);
	and	a, #'R'                       
	and	a, #'C'                       
	and	a, #(1)            
	and	a, #((524288))     
	and	a, #((524288)>>8)  
	and	a, #((524288)>>16) 
	and	a, #((524288)>>24) 
	and	a, #((3000))     
	and	a, #((3000)>>8)  
	and	a, #(0x0b)             
;	main.c: 37: return 0;
;	main.c: 38: }
	ret	#0x00
;	main.c: 40: void interrupt(void) __interrupt(0) {
;	-----------------------------------------
;	 function interrupt
;	-----------------------------------------
_interrupt:
	push	af
	mov	a, p
	push	af
;	main.c: 41: if (INTRQ & INTRQ_T16) {
	mov.io	a, __intrq
	and	a, #0x04
	ceqsn	a, #0x00
	goto	00109$
	goto	00103$
00109$:
;	main.c: 42: quarter_seconds++;
	mov	a, _quarter_seconds+0
	add	a, #0x01
	mov	_quarter_seconds+0, a
;	main.c: 43: INTRQ &= ~INTRQ_T16;
	set0.io	__intrq, #2
00103$:
;	main.c: 45: }
	pop	af
	mov	p, a
	pop	af
	reti
;	main.c: 47: int main(void) {
;	-----------------------------------------
;	 function main
;	-----------------------------------------
_main:
;	main.c: 53: T16M = 0b00111010;        // Use System (IHRC) clock source (524.288 kHz), /64, Interrupt on (rising) Bit 10
	mov	a, #0x3a
	mov.io	__t16m, a
;	main.c: 55: T16C = 0;
	clear	p
	stt16	p
;	main.c: 56: INTEN = INTEN_T16;
	mov	a, #0x04
	mov.io	__inten, a
;	main.c: 59: INTRQ = 0;
	mov	a, #0x00
	mov.io	__intrq, a
;	main.c: 60: __engint();
	engint
;	main.c: 62: while (1) {
00135$:
;	main.c: 63: if (quarter_seconds != prev_quarter_seconds) {
	mov	a, _quarter_seconds+0
	ceqsn	a, _prev_quarter_seconds+0
	goto	00216$
	goto	00135$
00216$:
;	main.c: 64: prev_quarter_seconds = quarter_seconds;
	mov	a, _quarter_seconds+0
	mov	_prev_quarter_seconds+0, a
;	main.c: 65: noTone();
	call	_noTone
;	main.c: 66: setPinPullup(UP_BTN_PIN);
	set1.io	__paph, #7
;	main.c: 67: setPinPullup(ST_BTN_PIN);
	set1.io	__paph, #6
;	main.c: 69: switch (mode_now) {
	mov	a, _mode_now+0
	ceqsn	a, #0x00
	goto	00218$
	goto	00108$
00218$:
	mov	a, _mode_now+0
	ceqsn	a, #0x01
	goto	00220$
	goto	00101$
00220$:
	mov	a, _mode_now+0
	ceqsn	a, #0x02
	goto	00222$
	goto	00127$
00222$:
	goto	00131$
;	main.c: 70: case MODE_CNT:
00101$:
;	main.c: 72: if (isPinLow(ST_BTN_PIN)) {
	mov.io	a, __pa
	and	a, #0x40
	ceqsn	a, #0x00
	goto	00103$
;	main.c: 73: mode_now = MODE_WAIT;
	clear	_mode_now+0
00103$:
;	main.c: 75: if ((quarter_seconds & 0b00000011) == 0b00000011) {
	clear	p
	mov	a, _quarter_seconds+0
	and	a, #0x03
	clear	p
	ceqsn	a, #0x03
	goto	00131$
	mov	a, p
	ceqsn	a, #0x00
	goto	00131$
;	main.c: 77: seconds++;
	inc	_seconds+0
	addc	_seconds+1
;	main.c: 78: if (seconds == set_seconds) {
	mov	a, _seconds+0
	ceqsn	a, _set_seconds+0
	goto	00131$
	mov	a, _seconds+1
	ceqsn	a, _set_seconds+1
	goto	00131$
;	main.c: 79: mode_now = MODE_END;
	mov	a, #0x02
	mov	_mode_now+0, a
;	main.c: 82: break;
	goto	00131$
;	main.c: 84: case MODE_WAIT:
00108$:
;	main.c: 85: if ((isPinLow(ST_BTN_PIN)) && (isPinLow(UP_BTN_PIN))) {
	mov.io	a, __pa
	and	a, #0x40
	ceqsn	a, #0x00
	goto	00124$
	mov.io	a, __pa
	and	a, #0x80
	ceqsn	a, #0x00
	goto	00124$
;	main.c: 87: seconds = 0;
	clear	_seconds+0
	clear	_seconds+1
;	main.c: 88: set_seconds = 0;
	clear	_set_seconds+0
	clear	_set_seconds+1
;	main.c: 89: tone_cnt = 0;            
	clear	_tone_cnt+0
;	main.c: 90: idle_cnt = IDLE_DUR;
	mov	a, #0x02
	mov	_idle_cnt+0, a
;	main.c: 91: tonePA3ND(6); // La
	mov	a, #0x06
	mov	_tonePA3ND_PARM_1+0, a
	call	_tonePA3ND
	goto	00131$
00124$:
;	main.c: 93: } else if ((isPinHigh(ST_BTN_PIN)) && (isPinLow(UP_BTN_PIN))) {
	mov.io	a, __pa
	and	a, #0x40
	ceqsn	a, #0x00
	goto	00223$
	goto	00120$
00223$:
	mov.io	a, __pa
	and	a, #0x80
	ceqsn	a, #0x00
	goto	00120$
;	main.c: 95: set_seconds+=60;
	mov	a, _set_seconds+0
	add	a, #0x3c
	mov	p, a
	mov	a, _set_seconds+1
	addc	a
	mov	_set_seconds+1, a
	mov	a, p
	mov	_set_seconds+0, a
;	main.c: 96: idle_cnt = IDLE_DUR;
	mov	a, #0x02
	mov	_idle_cnt+0, a
;	main.c: 97: tonePA3ND(tone_cnt%18+1); // 1to18
	mov	a, _tone_cnt+0
	mov	__modsint_PARM_1+0, a
	clear	__modsint_PARM_1+1
	mov	a, #0x12
	mov	__modsint_PARM_2+0, a
	clear	__modsint_PARM_2+1
	call	__modsint
	add	a, #0x01
	mov	_tonePA3ND_PARM_1+0, a
	call	_tonePA3ND
;	main.c: 98: tone_cnt++;
	inc	_tone_cnt+0
	goto	00131$
00120$:
;	main.c: 99: } else if ((isPinLow(ST_BTN_PIN)) && (isPinHigh(UP_BTN_PIN)) && (set_seconds != 0)) {
	mov.io	a, __pa
	and	a, #0x40
	ceqsn	a, #0x00
	goto	00115$
	mov.io	a, __pa
	and	a, #0x80
	ceqsn	a, #0x00
	goto	00224$
	goto	00115$
00224$:
	mov	a, _set_seconds+0
	or	a, _set_seconds+1
	ceqsn	a, #0x00
	goto	00225$
	goto	00115$
00225$:
;	main.c: 101: mode_now = MODE_CNT;
	mov	a, #0x01
	mov	_mode_now+0, a
;	main.c: 102: idle_cnt = IDLE_DUR;
	mov	a, #0x02
	mov	_idle_cnt+0, a
;	main.c: 104: tonePA3ND(8); // Do
	mov	a, #0x08
	mov	_tonePA3ND_PARM_1+0, a
	call	_tonePA3ND
	goto	00131$
00115$:
;	main.c: 107: else if ((isPinHigh(ST_BTN_PIN)) && (isPinHigh(UP_BTN_PIN))) {
	mov.io	a, __pa
	and	a, #0x40
	ceqsn	a, #0x00
	goto	00226$
	goto	00131$
00226$:
	mov.io	a, __pa
	and	a, #0x80
	ceqsn	a, #0x00
	goto	00227$
	goto	00131$
00227$:
;	main.c: 108: idle_cnt--;
	dzsn	_idle_cnt+0
	goto	00131$
;	main.c: 109: if (idle_cnt == 0) {
;	main.c: 110: PADIER = (uint8_t)((1<<UP_BTN_PIN_BIT)|(1<<ST_BTN_PIN_BIT));
	mov	a, #0xc0
	mov.io	__padier, a
;	main.c: 111: noTone(); // tone off
	call	_noTone
;	main.c: 113: __stopexe(); 
	stopexe
	nop
;	main.c: 119: break;
	goto	00131$
;	main.c: 121: case MODE_END:
00127$:
;	main.c: 123: if (isPinLow(ST_BTN_PIN)) {
	mov.io	a, __pa
	and	a, #0x40
	ceqsn	a, #0x00
	goto	00129$
;	main.c: 124: seconds = 0;
	clear	_seconds+0
	clear	_seconds+1
;	main.c: 125: noTone();
	call	_noTone
;	main.c: 126: mode_now = MODE_WAIT;
	clear	_mode_now+0
	goto	00131$
00129$:
;	main.c: 128: tonePA3ND(17); // Si 5
	mov	a, #0x11
	mov	_tonePA3ND_PARM_1+0, a
	call	_tonePA3ND
;	main.c: 133: }  
00131$:
;	main.c: 135: clearPinPullup(ST_BTN_PIN);
	set0.io	__paph, #6
;	main.c: 136: clearPinPullup(UP_BTN_PIN);
	set0.io	__paph, #7
	goto	00135$
;	main.c: 139: }
	ret
	.area CODE
	.area CONST
	.area CABS (ABS)

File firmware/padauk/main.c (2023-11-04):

#include <pdk/device.h>
#include <easy-pdk/calibrate.h>
#include "util.h"
#include "./Padauk-tone/tone.h"

#define UP_BTN_PIN_BIT 7
#define ST_BTN_PIN_BIT 6

#define UP_BTN_PIN PA,7
#define ST_BTN_PIN PA,6
#define BUZZER_PIN PA,3

#define MODE_WAIT 0
#define MODE_CNT  1
#define MODE_END  2

#define IDLE_DUR 2 // 0.25*2=0.5sec

volatile uint8_t quarter_seconds;
uint8_t prev_quarter_seconds = 0;
uint8_t mode_now = MODE_WAIT;
uint8_t tone_cnt = 0;
uint16_t seconds = 0, set_seconds = 0;
uint8_t idle_cnt = IDLE_DUR; 

unsigned char _sdcc_external_startup(void) {
    
#if (F_CPU == 524288)
  PDK_SET_SYSCLOCK(SYSCLOCK_IHRC_500KHZ);
  EASY_PDK_CALIBRATE_IHRC(524288, TARGET_VDD_MV);
#elif (F_CPU == 65536)
  PDK_SET_SYSCLOCK(SYSCLOCK_ILRC);
  EASY_PDK_CALIBRATE_ILRC(65536, TARGET_VDD_MV);
#else
  #error "Unknown F_CPU"
#endif
    return 0;
}

void interrupt(void) __interrupt(0) {
    if (INTRQ & INTRQ_T16) {
        quarter_seconds++;
        INTRQ &= ~INTRQ_T16;
    }
}

int main(void) {
    

    #if (F_CPU == 65536)
		T16M = 0b11010001;        // Use ILRC clock source (65.536 kHz), /16, Interrupt on (rising) Bit 9
	#elif (F_CPU == 524288)
		T16M = 0b00111010;        // Use System (IHRC) clock source (524.288 kHz), /64, Interrupt on (rising) Bit 10
	#endif
    T16C = 0;
	INTEN = INTEN_T16;

    // Enable Global Interrupt
    INTRQ = 0;
	__engint();

    while (1) {
        if (quarter_seconds != prev_quarter_seconds) {
            prev_quarter_seconds = quarter_seconds;
            noTone();
            setPinPullup(UP_BTN_PIN);
            setPinPullup(ST_BTN_PIN);

            switch (mode_now) {
            case MODE_CNT:

            if (isPinLow(ST_BTN_PIN)) {
                mode_now = MODE_WAIT;
            }
            if ((quarter_seconds & 0b00000011) == 0b00000011) {
                // once a second
                seconds++;
                if (seconds == set_seconds) {
                    mode_now = MODE_END;
                }
            }
            break;

            case MODE_WAIT:
            if ((isPinLow(ST_BTN_PIN)) && (isPinLow(UP_BTN_PIN))) {
                // reset counters
                seconds = 0;
                set_seconds = 0;
                tone_cnt = 0;            
                idle_cnt = IDLE_DUR;
                tonePA3ND(6); // La
                
            } else if ((isPinHigh(ST_BTN_PIN)) && (isPinLow(UP_BTN_PIN))) {
                // set seconds
                set_seconds+=60;
                idle_cnt = IDLE_DUR;
                tonePA3ND(tone_cnt%18+1); // 1to18
                tone_cnt++;
            } else if ((isPinLow(ST_BTN_PIN)) && (isPinHigh(UP_BTN_PIN)) && (set_seconds != 0)) {
                //start
                mode_now = MODE_CNT;
                idle_cnt = IDLE_DUR;
                //tone_cnt = 0;
                tonePA3ND(8); // Do
            } 
            #if 1
            else if ((isPinHigh(ST_BTN_PIN)) && (isPinHigh(UP_BTN_PIN))) {
                idle_cnt--;
                if (idle_cnt == 0) {
                    PADIER = (uint8_t)((1<<UP_BTN_PIN_BIT)|(1<<ST_BTN_PIN_BIT));
                    noTone(); // tone off

                    __stopexe(); 
                    // datasheet says PAC should be '1' but '1' means output.
                    // result: PAC should be '0'. datasheet was wrong.
                }
            }
            #endif
            break;

            case MODE_END:
            
            if (isPinLow(ST_BTN_PIN)) {
                seconds = 0;
                noTone();
                mode_now = MODE_WAIT;
            } else {
                tonePA3ND(17); // Si 5

            }
            break;

            }  

            clearPinPullup(ST_BTN_PIN);
            clearPinPullup(UP_BTN_PIN);
        }
    }
}

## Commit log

2023-11-04 add pcb&firmware
    [clover_timer.kicad_pcb, clover_timer.kicad_sch]
2023-11-04 add case
    [bottom_rev0_1.ipt, bottom_rev0f.stl, jigu_laser_rev2.dxf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]
2023-11-13 update pcb, add docs
    [bottom_rev0_1.ipt, bottom_rev0f.ipt, clover_timer.kicad_pcb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]
2023-11-24 update docs
    [clover_timer.kicad_sch]
